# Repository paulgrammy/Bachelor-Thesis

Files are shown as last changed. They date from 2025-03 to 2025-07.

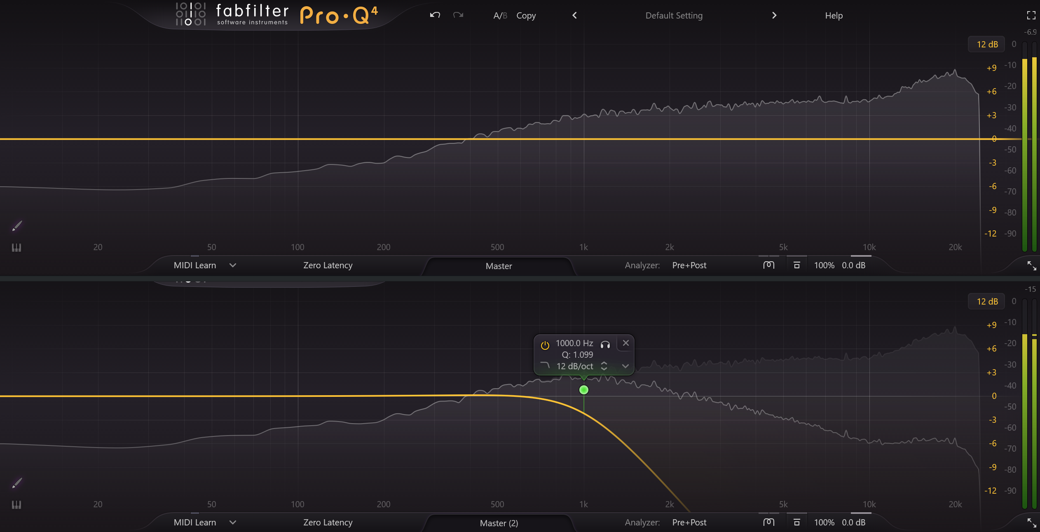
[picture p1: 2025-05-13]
doc/LPF over White Noise Visualised.png

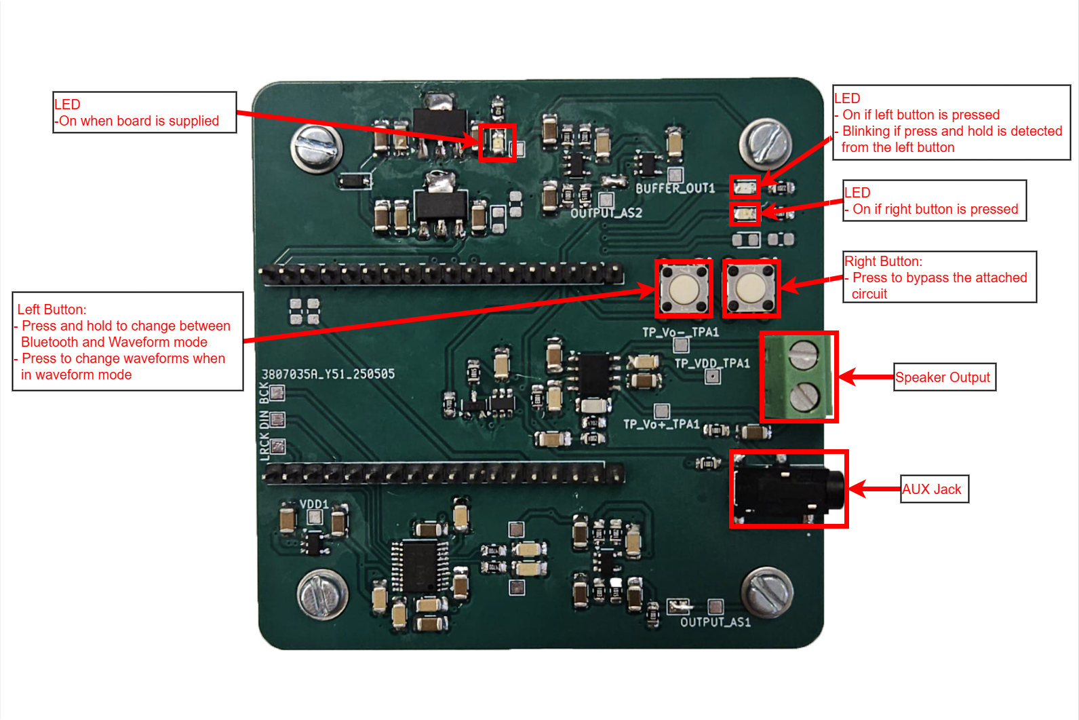
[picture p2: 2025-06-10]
doc/PCB_Functionality.png

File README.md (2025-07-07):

# Bachelor-Thesis

## Introduction and motivation
In recent years, there has been a growing emphasis on learning through hands-on experimentation, particularly in engineering education. One effective way to explore the behavior of electrical components is by using sound signals, which provide an intuitive and immediate way to observe phenomena such as filtering and waveshaping. \newline

My body of work builds on my prior student research project that exemplified this approach using filters. In the project, a prototype was built that takes Bluetooth audio from a source and feeds it through filters studied in electronics labs, thus enabling a better understanding of signal processing concepts. The board then passes the resulting sound to an audio device such as headphones or speakers.

## Requirements and considerations
System-wise, the board shall take +15 V and step it down to supply voltages required by each IC. A 2-layered design is shown, featuring four mounting pins for FestoBoard compatibility. Below, a block diagram is shown, underlying the ICs used for my implementation:

Thesis_Blockdiagram

## Physical view
SMD components alongside SOIC packages for ICs have been used to allow space for all components. Alongside passives and ICs, some buttons and LEDs have been added for user interaction. These shall be handled by the ESP32:

Thesis_PCB

## Software
The ESP32 found on the PCB acts as either:
1) A Bluetooth receiver using [pschatzmann's A2DP library](https://github.com/pschatzmann/ESP32-A2DP);
2) A waveform generator, interfacing via I2S with the DAC to output one of four different waveforms.

FreeRTOS tasks are used to handle the different states of the code:

State Machine Diagram Bachelor Thesis

## Repo structure
* doc: Pictures, Datasheets, Files documenting different aspects of the project
* footprints: different footprints used in the PCB layout
* schematics: KiCAD schematic and layout, and the LTSpice simulation of Op-Amp stages can be found here
* software: the code implementation

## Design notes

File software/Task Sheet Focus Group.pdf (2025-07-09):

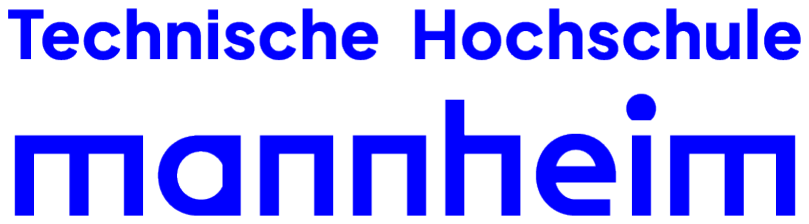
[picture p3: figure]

## Faculty of Electrical Engineering

# Electronics lab

# Signal processing using Audio

made by

Paul Gramescu (2120205)

supervised by

Prof. Dr. Simon Effler

Focus Group

## 1 Objective

- Use the Bluetooth audio board on a FestoBoard to explore the real-time effects of analog filters on audio signals
- Learn how different filter types shape sound and evaluate the usability of the system as a learning tool.

## 2 User Guide

The board used in this lab is meant to feed an audio signal into analog circuits. It is designed to be placed on FestoBoards and features four pins. Below, a photo of the board, along with highlighted important features:

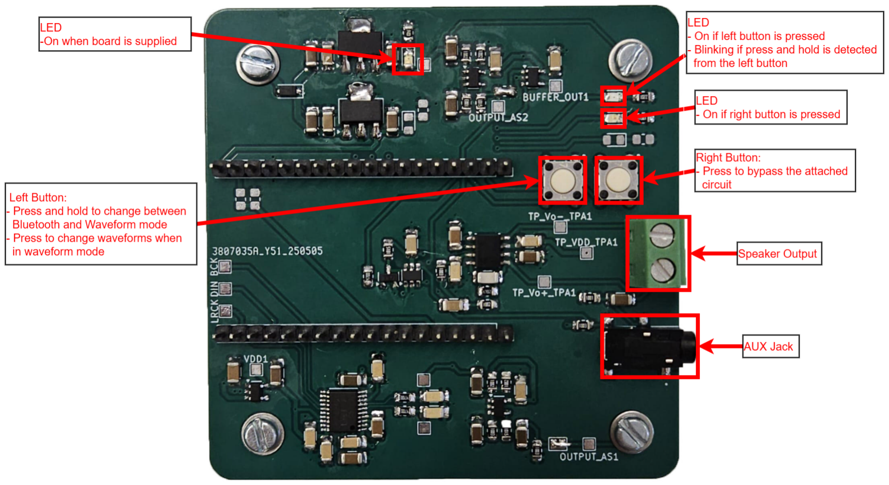
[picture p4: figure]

Abbildung 1: PCB Functionality

Hochschule Mannheim
9. Juni 2025

2

Focus Group

## 3 Setup Instructions

1. Configure the power supply: +15V with a 350mA current limit
2. Connect the audio board:

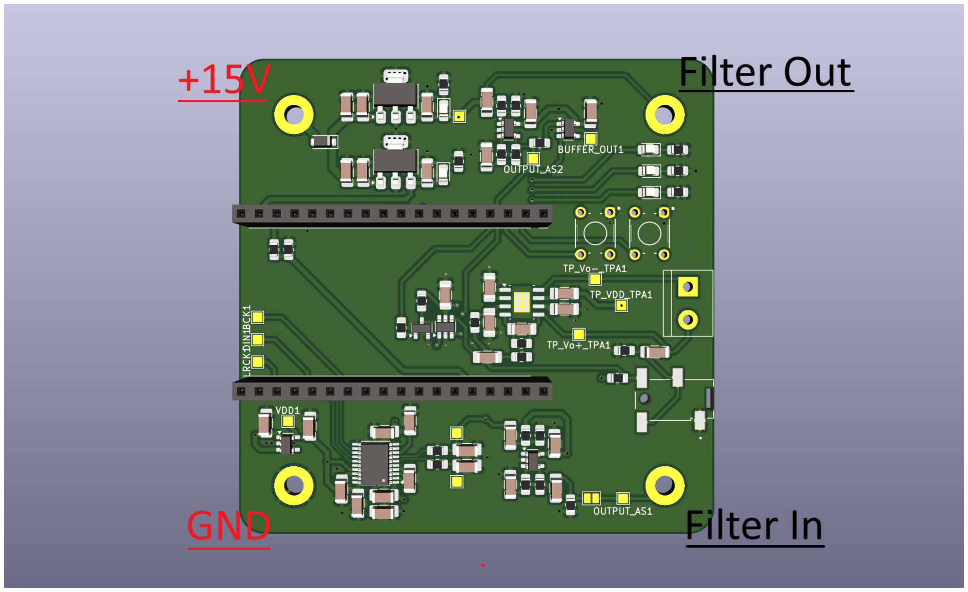
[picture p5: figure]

3. Power on the FestoBoard. If the PCB is connected properly, the topmost LED will turn on, as shown in the user guide section.
4. Connect your phone to the board that corresponds to your desk number
5. Test by playing some audio (e.g., sine sweep, music, voice)
Tip: Press and hold the left button to cycle between Bluetooth/Waveform mode.

If in waveform mode, briefly pressing the same button will cycle through various waveforms. Pressing the right button will bypass the filter circuit.

Hochschule Mannheim
9. Juni 2025

3

Focus Group

## 4 Task No. 1: Filtering high-end frequencies

This task will focus on the effects of low-pass filters on audio signals.

1. Assemble the following active, second-order, low-pass filter:
R1 = 3.2k, R2 = R3 = 10k, C1 = 470nF, C2 = 10nF

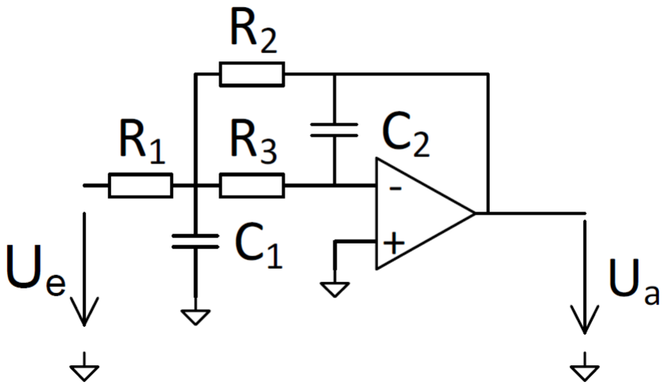
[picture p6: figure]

Abbildung 2: 2nd Order LPF, fc=230Hz

2. Connect Ue to Filter In and Ua to the Filter Out pins of the board
3. Power on the FestoBoard, connect your phone, and verify connectivity
4. Play an audio sample (Ex. Bees Gees - Stayin’ Alive, white noise, a baby crying).
5. Listen and analyse, what do you hear? Why is this happening? Argue your

reasoning
Tip: Use the Bypass function to identify the effect
6. For a more controlled test, use the on-board waveform generator; try cycling between the waveforms

Hochschule Mannheim
9. Juni 2025

4

Focus Group

## 5 Task No. 2: Exploring Filter Orders and Roll-off

This task will explore various filter topologies and their effects.

There are different ways to implement filters. For this case study, three different types of low-pass filters will be used to study their roll-off regions.

IN | OUT

Abbildung 3: 1st-Order, Passive

IN | OUT

Abbildung 4: 2nd-Order, Passive

Abbildung 5: 2nd-Order, Active, same as Task 1

Dimension the circuits with a 230 Hz corner frequency. Use the 5th waveform type (press the right button 4 times). Listen to the output signal and notice the differences

in roll-off. Which topology would be better to use? Why?

Tip: try building a 3rd-order LPF by connecting a 1st-order filter with a 2nd-order in series. What should be the order in which you connect them?

Hochschule Mannheim
9. Juni 2025

5

Focus Group

## 6 Task No. 3: Filtering an unwanted frequency component

This task will show how filters are used to remove unwanted information from a signal.

Say you have a sensor that sends you analog data at a rate of 1.5 kHz. Unfortunately, due to incompetent wiring from your Intern, you receive an additional parasitic, low-frequency component in your signal. This will heavily affect the precision of your measurement and ruin your career. Your task is to analyse the incoming signal and filter the unwanted component:

1. Power on the board and activate Waveform mode
2. Cycle to Waveform 4 (press the button 3 times)
3. Listen to this signal, what do you hear?
4. Analyse in detail: use the Math − > FFT function of the Oscilloscope to analyse

the frequency spectrum
Tip: set the center as 10kHz and the maximum as 20kHz when setting the FFT
5. Conceptualise a second order filter to address the problem
Tip: frequency lies somewhere under your main signal in the spectrum, what does that mean? What would be the cutoff frequency of the filter?
6. Check your result by comparing the un-/bypassed signal path

Hochschule Mannheim
9. Juni 2025

6

Focus Group

### 6.1 Feedback Box

As this was a Focus Group, you are now asked to provide feedback on the exercises, setup, and the board itself.

Feedback:

What did you enjoy in this lab?

What could be improved?

Any additional comments?

Hochschule Mannheim
9. Juni 2025

7

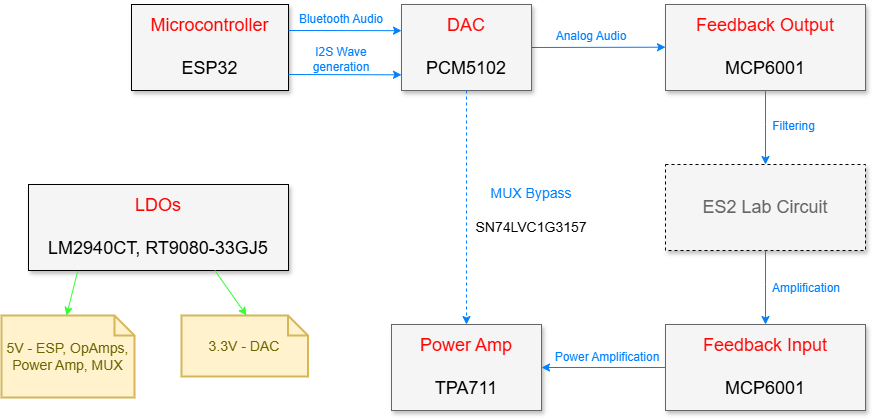
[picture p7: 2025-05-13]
doc/Thesis_Blockdiagram.png

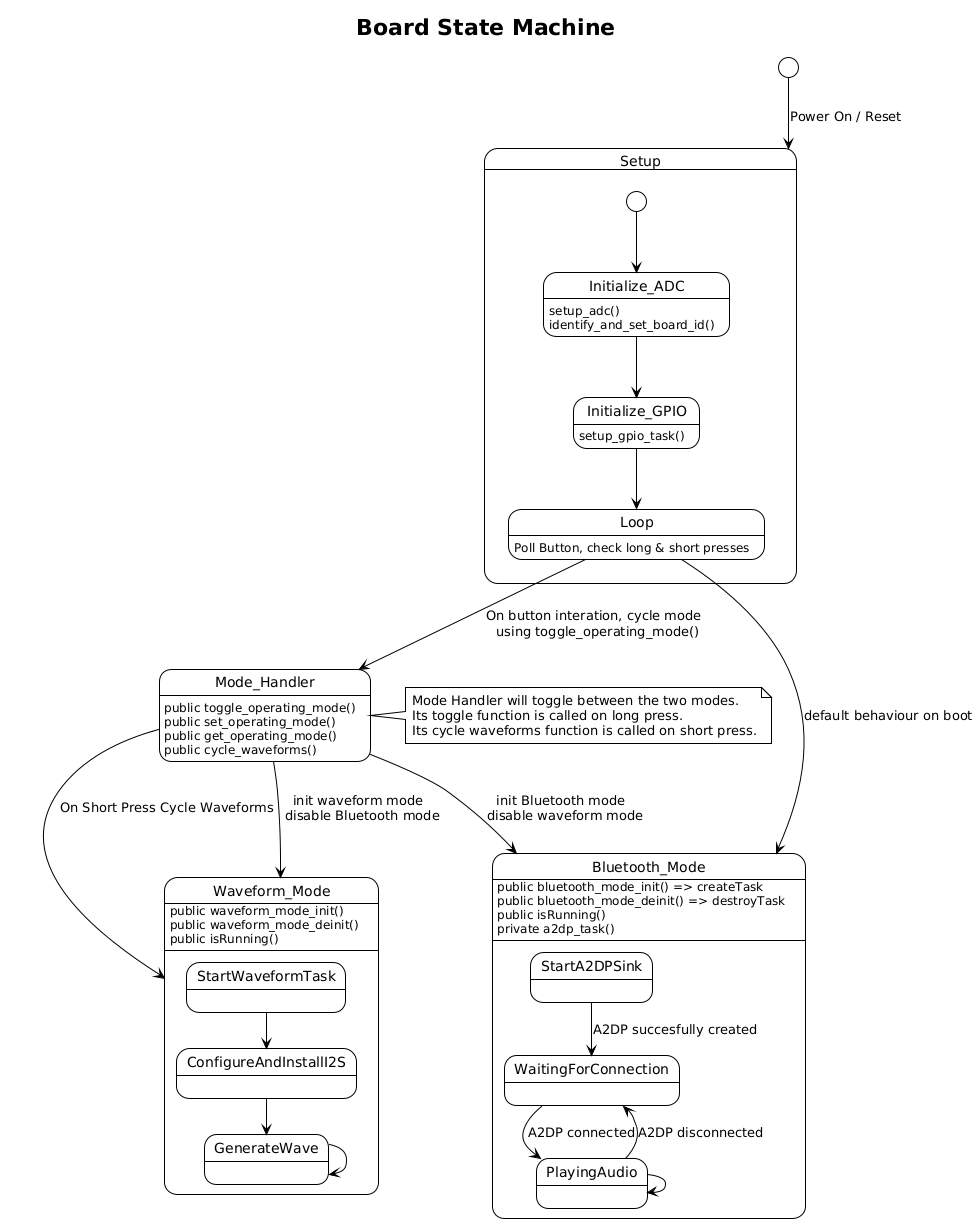
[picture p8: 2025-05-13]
doc/State Machine Diagram Bachelor Thesis.png

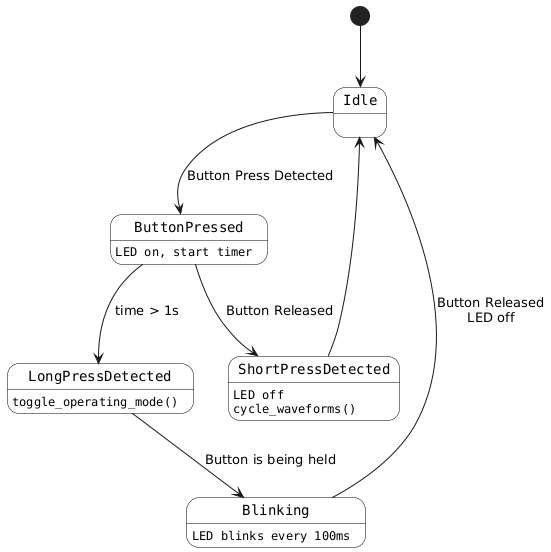
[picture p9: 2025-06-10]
doc/Button Polling State Diagram.png

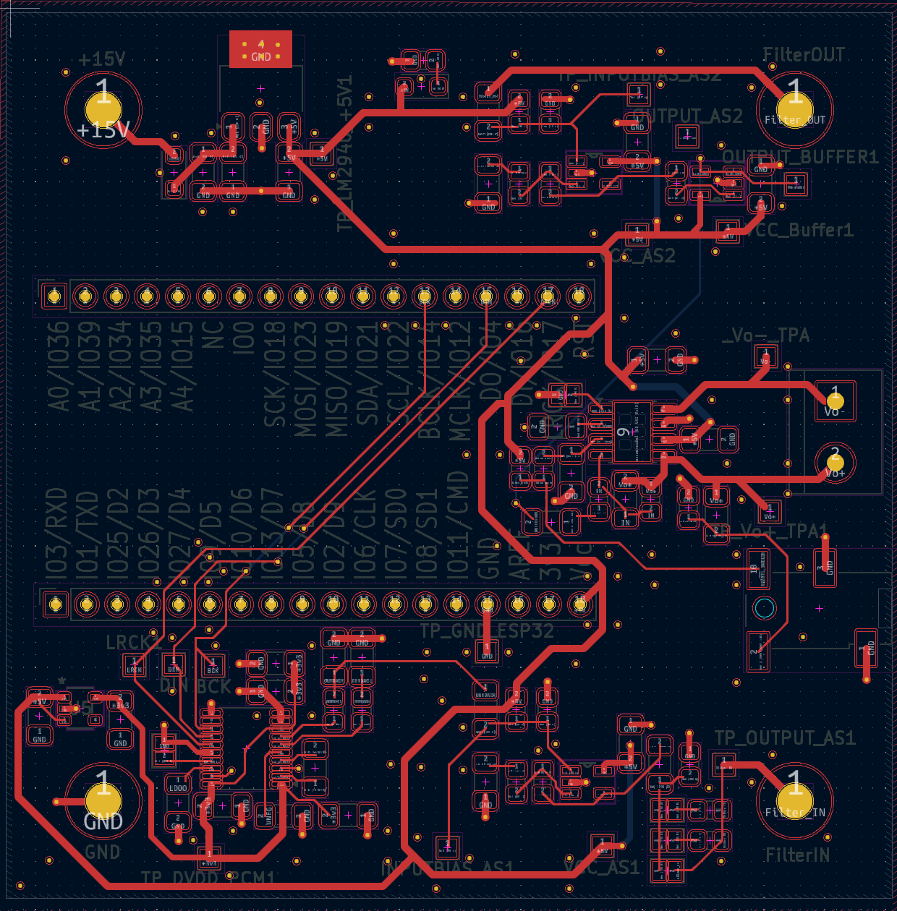
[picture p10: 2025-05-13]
doc/Studienarbeit_PCB.png

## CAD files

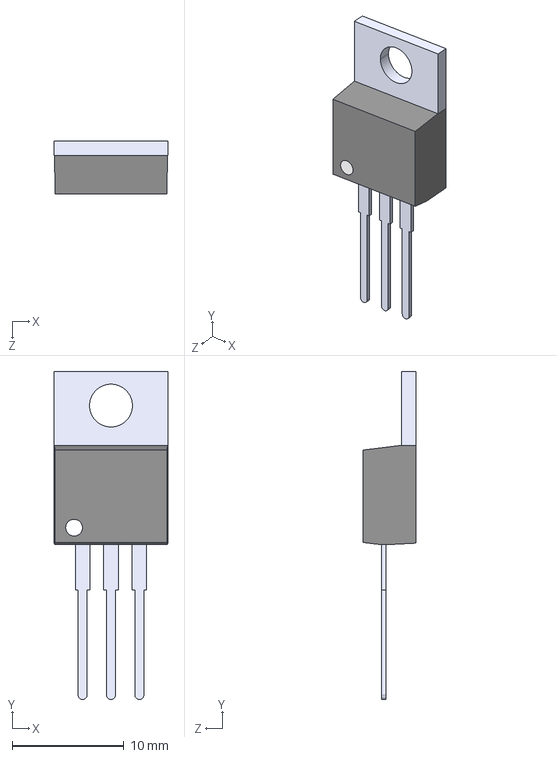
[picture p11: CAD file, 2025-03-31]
footprints/LM2940-5.0/LM2940CT-5.0.step
10.2 x 29.3 x 4.70 mm

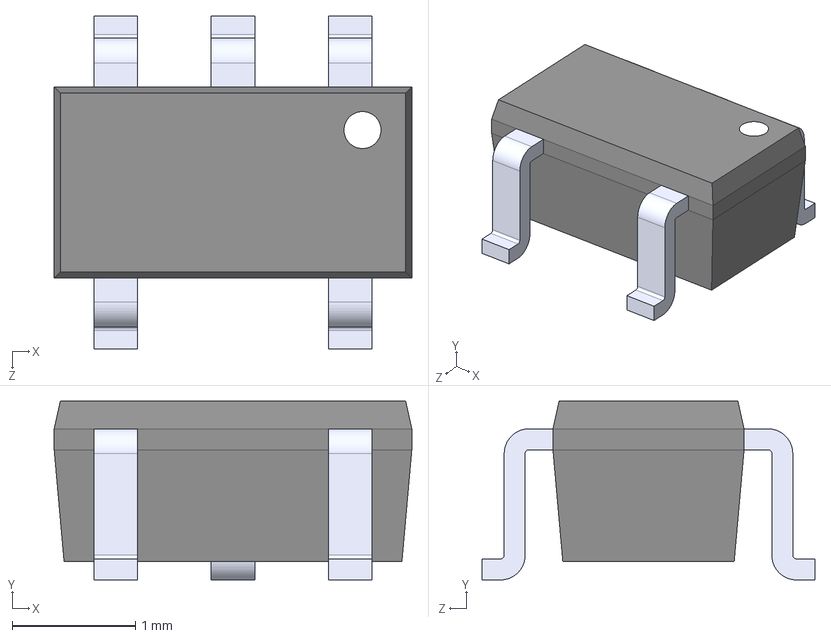
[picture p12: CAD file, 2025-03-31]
footprints/MCP6001UT-1_OT/MCP6001UT-I_OT.step
2.90 x 1.45 x 2.70 mm

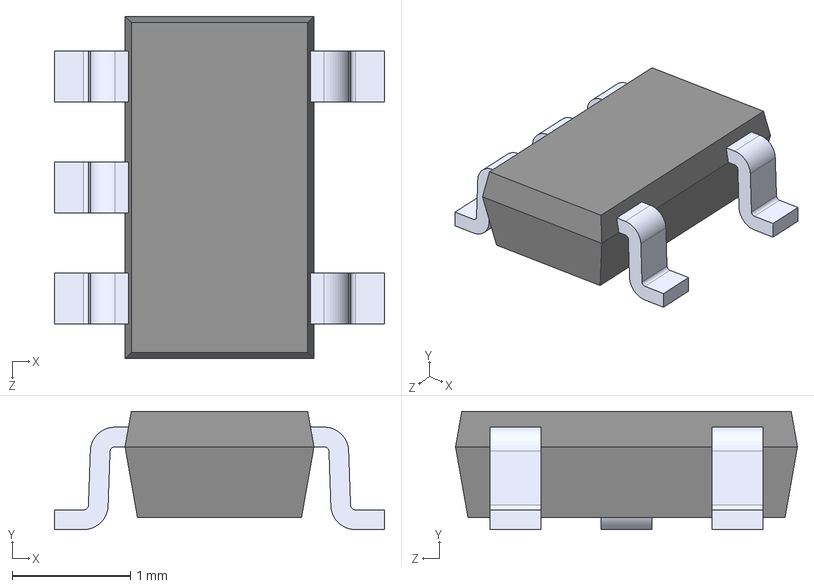
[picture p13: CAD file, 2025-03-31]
footprints/RT9080-33GJ5/RT9080-33GJ5.step
2.80 x 1.00 x 2.90 mm

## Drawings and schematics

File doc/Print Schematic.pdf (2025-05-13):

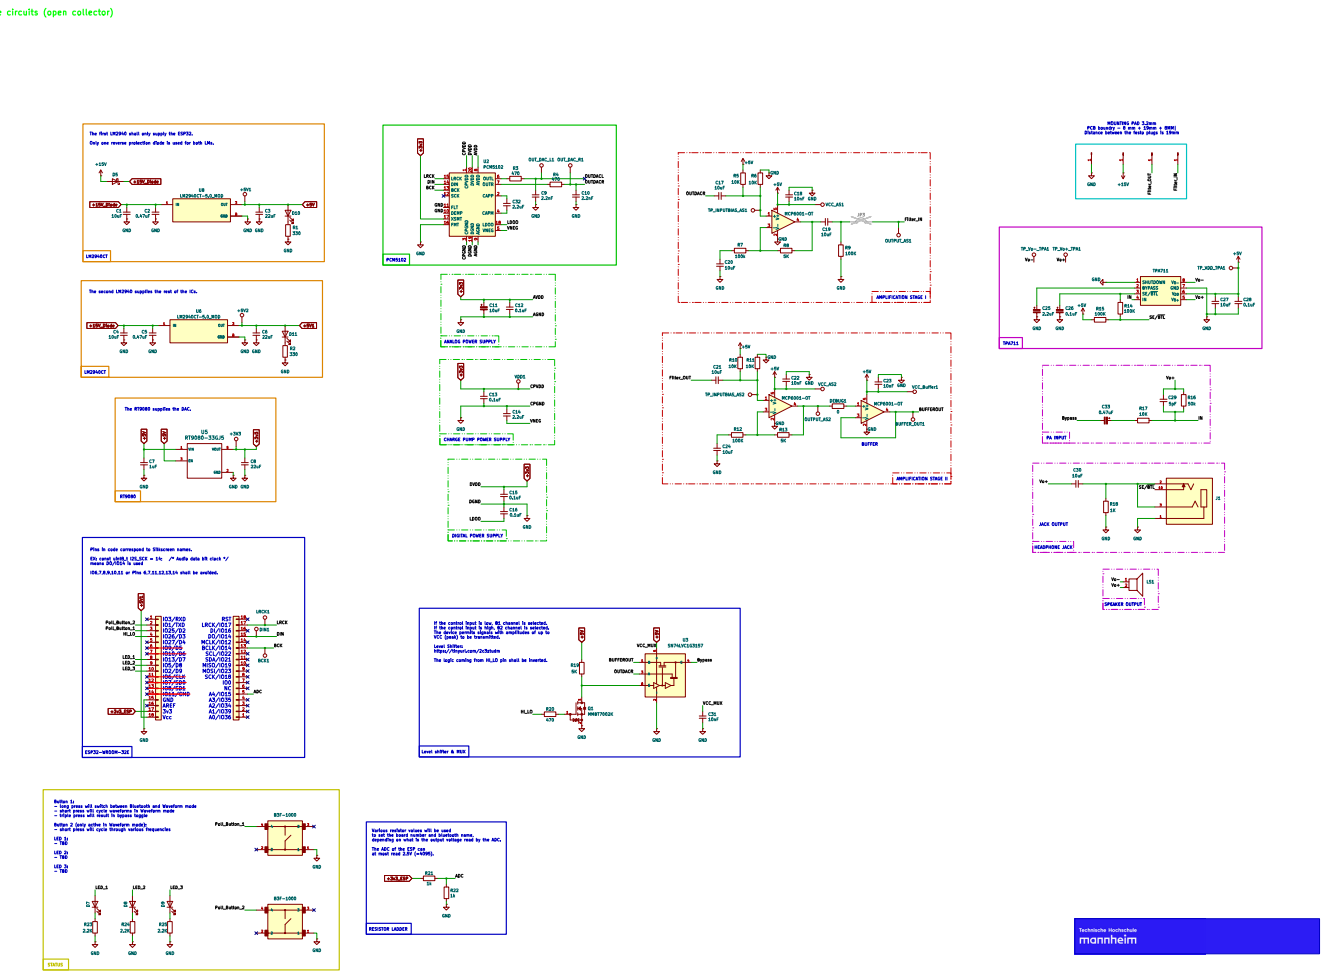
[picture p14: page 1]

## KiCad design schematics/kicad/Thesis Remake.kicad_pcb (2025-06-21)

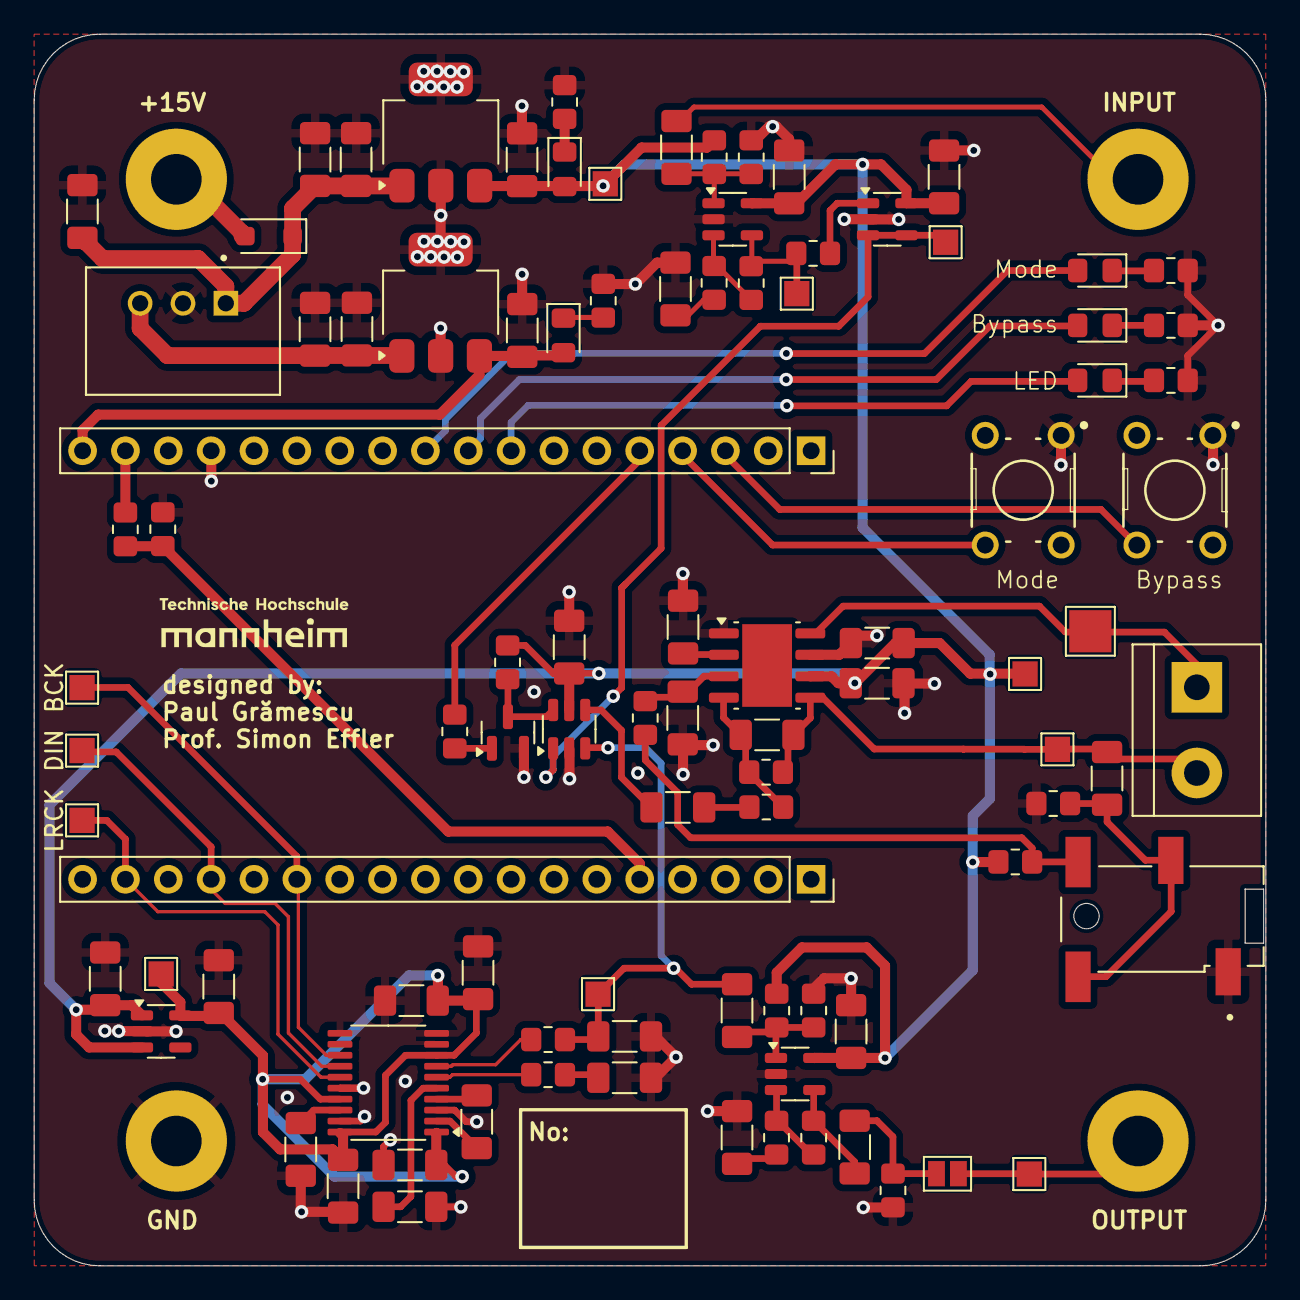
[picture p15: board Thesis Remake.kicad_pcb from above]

Board: 2 copper layers, 73.0 x 73.0 mm, 100 parts (0 on the bottom side), 55 nets.

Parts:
+5V1: TestPoint; TestPoint_Pad_1.5x1.5mm
BCK: TestPoint; TestPoint_Pad_1.5x1.5mm
BUFFER_OUT1: TestPoint; TestPoint_Pad_1.5x1.5mm
C1, C4, C11, C17, C19, C20, C21, C24, C27, C30, C34: 10uF; C_1206_3216Metric_Pad1.33x1.80mm_HandSolder
C2, C5, C33: 0.47uF; C_1206_3216Metric_Pad1.33x1.80mm_HandSolder
C3, C6, C8: 22uF; C_1206_3216Metric_Pad1.33x1.80mm_HandSolder
C7: 1uF; C_1206_3216Metric_Pad1.33x1.80mm_HandSolder
C9, C10: 2.2nF; C_1206_3216Metric_Pad1.33x1.80mm_HandSolder
C12, C13, C15, C16, C26, C28: 0.1uF; C_1206_3216Metric_Pad1.33x1.80mm_HandSolder
C14, C25, C32: 2.2uF; C_1206_3216Metric_Pad1.33x1.80mm_HandSolder
C18, C22, C23, C31: 10nF; C_1206_3216Metric_Pad1.33x1.80mm_HandSolder
C29: 5pF; C_1206_3216Metric_Pad1.33x1.80mm_HandSolder
D5: D_Schottky; D_SOD-123F
D7, D8, D9, D10, D11: LED; LED_0805_2012Metric_Pad1.15x1.40mm_HandSolder
DEBUG1: 0; R_0805_2012Metric_Pad1.20x1.40mm_HandSolder
DIN: TestPoint; TestPoint_Pad_1.5x1.5mm
J1: SJ2-35853B-SMT-TR; CUI_SJ2-35853B-SMT-TR
J2, J3: Conn_01x18; PinSocket_1x18_P2.54mm_Vertical
J4, J5, J6, J7: Conn_01x01_Pin; FestoBoard_Drill_Hole
JP3: Jumper_2_Open; SolderJumper-2_P1.3mm_Open_Pad1.0x1.5mm
LRCK: TestPoint; TestPoint_Pad_1.5x1.5mm
LS1: Speaker; TerminalBlock_bornier-2_P5.08mm
OUTPUT_AS1, OUTPUT_AS2: TestPoint; TestPoint_Pad_1.5x1.5mm
OUT_DAC_R1: TestPoint; TestPoint_Pad_1.5x1.5mm
PS1: TSR_0.5-2465; CONV_TSR_0.5-2465
Q1: MMBT7002K; SOT-23
R1, R2: 330; R_0805_2012Metric_Pad1.20x1.40mm_HandSolder
R3, R4, R20: 470; R_0805_2012Metric_Pad1.20x1.40mm_HandSolder
R5, R6, R10, R11, R17: 10K; R_0805_2012Metric_Pad1.20x1.40mm_HandSolder
R7: 100k; R_0805_2012Metric_Pad1.20x1.40mm_HandSolder
R8, R13, R19: 5K; R_0805_2012Metric_Pad1.20x1.40mm_HandSolder
R9, R12, R14, R15: 100K; R_0805_2012Metric_Pad1.20x1.40mm_HandSolder
R16: 50k; R_0805_2012Metric_Pad1.20x1.40mm_HandSolder
R18: 1K; R_0805_2012Metric_Pad1.20x1.40mm_HandSolder
R21, R22: 1k; R_0805_2012Metric_Pad1.20x1.40mm_HandSolder
R23, R24, R25: 2.2K; R_0805_2012Metric_Pad1.20x1.40mm_HandSolder
S1, S2: B3F-1000; SW_B3F-1000
TP_VDD_TPA1: TestPoint; TestPoint_Pad_1.5x1.5mm
U2: PCM5102; TSSOP-20_4.4x6.5mm_P0.65mm
U3: SN74LVC1G3157; SOT-23-6
U5: RT9080-33GJ5; SOT-23-5
U6, U8: LM2940CT-5.0_MOD; SOT-223
U7: TPA711; Texas_R-PDSO-G8_EP2.95x4.9mm_Mask2.4x3.1mm
U9, U10, U11: MCP6001-OT; SOT-23-5
VDD1: TestPoint; TestPoint_Pad_1.5x1.5mm
Vo+1: TestPoint; TestPoint_Pad_1.5x1.5mm
Vo-1: TestPoint; TestPoint_Pad_2.5x2.5mm

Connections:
+3v3: C8.2, C11.1, C12.2, C13.2, C15.2, U2.1 (CPVDD), U2.8 (AVDD), U2.17 (XSMT), U2.20 (DVDD), U5.5 (VOUT), VDD1.1
+3v3_ESP: J2.17, R21.2
+5V: +5V1.1, C3.2, C7.2, C18.2, C22.2, C23.2, C27.1, C28.1, C31.1, D10.2 (A), R5.2, R10.2, R15.2, R19.2, TP_VDD_TPA1.1, U3.5 (+), U5.1 (VIN), U5.3 (EN), U7.6 (V_{DD}), U8.3 (OUT), U9.5 (V+), U10.5 (V+), U11.5 (V+)
+5V1: C6.2, D11.2 (A), J2.18, U6.3 (OUT)
+6.5V: C4.1, C5.2, PS1.3 (+VOUT), U6.1 (IN)
+15V: D5.2 (A), J5.1
+15V_Diode: C1.1, C2.2, C34.1, D5.1 (K), PS1.1 (+VIN), U8.1 (IN)
/ADC: J3.5, R21.1, R22.1
/BCK: BCK.1, J3.13, U2.13 (BCK)
/BUFFEROUT: BUFFER_OUT1.1, U3.1 (B), U11.3 (-), U11.4
/Bypass: C33.2, U3.4 (C)
/DIN: DIN.1, J3.15, U2.14 (DIN)
/Filter_IN: J7.1, JP3.2 (B), OUTPUT_AS1.1
/Filter_OUT: C21.1, J6.1
/HI_LO: J2.5, R20.1
/IN: C29.1, R16.2, R17.2, U7.4 (IN)
/LDOO: C16.1, U2.18 (LDOO)
/LED_1: D7.2 (A), J2.8
/LED_2: D8.2 (A), J2.9
/LED_3: D9.2 (A), J2.10
/LRCK: J3.17, LRCK.1, U2.15 (LRCK)
/OUTDACL: C9.1, R3.2
/OUTDACR: C10.1, C17.1, OUT_DAC_R1.1, R4.2, U3.3 (A)
/Poll_Button_1: J2.4, S1.4
/Poll_Button_2: J2.3, S2.4
/SE/~BTL: J1.10, R14.1, R15.1
/VNEG: C14.2, U2.5 (VNEG)
/Vo+: C29.2, C30.1, LS1.2, R16.1, U7.5 (V_{O+}), Vo+1.1
/Vo-: LS1.1, U7.8 (V_{O-}), Vo-1.1
GND: C1.2, C2.1, C3.1, C4.2, C5.1, C6.1, C7.1, C8.1, C9.2, C10.2, C11.2, C12.1, C13.1, C14.1, C15.1, C16.2, C18.1, C20.1, C22.1, C23.1, C24.1, C25.2, C26.2, C27.2, C28.2, C31.2, C34.2, J1.1, J2.15, J4.1, PS1.2 (GND), Q1.2, R1.1, R2.1, R6.2, R9.1, R11.2, R18.2, R22.2, R23.1, R24.1, R25.1, S1.1, S2.1, U2.3 (CPGND), U2.9 (AGND), U2.10 (DEMP), U2.11 (FLT), U2.16 (FMT), U2.19 (DGND), U3.2 (-), U5.2 (GND), U6.2 (GND), U6.4 (GND), U7.1 (SHUTDOWN), U7.7 (GND), U8.2 (GND), U8.4 (GND), U9.2 (V-), U10.2 (V-), U11.2 (V-)
unnamed: C19.2, R8.2, U9.4
unnamed: C20.2, R7.1
unnamed: C24.2, R12.1
unnamed: C30.2, J1.2, J1.3, R18.1
unnamed: C33.1, R17.1
unnamed: D7.1 (K), R23.2
unnamed: D8.1 (K), R24.2
unnamed: D9.1 (K), R25.2
unnamed: D10.1 (K), R1.2
unnamed: D11.1 (K), R2.2
unnamed: DEBUG1.1, OUTPUT_AS2.1, R13.2, U10.4
unnamed: C19.1, JP3.1 (A), R9.2
unnamed: Q1.1, R20.2
unnamed: C32.2, U2.4 (CAPM)
unnamed: C32.1, U2.2 (CAPP)
unnamed: R3.1, U2.6 (OUTL)
unnamed: R4.1, U2.7 (OUTR)
unnamed: Q1.3, R19.1, U3.6 (S)
unnamed: C25.1, U7.2 (BYPASS)
unnamed: C26.1, R14.2, U7.3 (SE/~BTL)
unnamed: C17.2, R5.1, R6.1, U9.1 (+)
unnamed: R7.2, R8.1, U9.3 (-)
unnamed: C21.2, R10.1, R11.1, U10.1 (+)
unnamed: R12.2, R13.1, U10.3 (-)
unnamed: DEBUG1.2, U11.1 (+)

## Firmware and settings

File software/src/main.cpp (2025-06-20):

#include <Arduino.h>
#include <ESP_I2S.h>
#include <esp_log.h>

#include "gpio_task.h"
#include "adc_handler.h"
#include "switch_handler.h"
#include "driver/uart.h"

static const char *TAG_MAIN = "MAIN";

void setup()
{
    // Disable UART0 to free GPIO1 before setting up the bypass task, required for button 
    // ESP_LOGI(TAG_MAIN, "Disabling UART...");
    // uart_driver_delete(UART_NUM_0);
    // gpio_reset_pin(GPIO_NUM_1);

    ESP_LOGI(TAG_MAIN, "Starting setup...");

    // Setup ADC
    ESP_LOGI(TAG_MAIN, "Setting up ADC...");
    if (setup_adc() == false)
    {
        ESP_LOGE(TAG_MAIN, "Failed to setup ADC!");
    }
    else
    {
        // ID the board based on voltage
        ESP_LOGI(TAG_MAIN, "Identified board: %s", get_board_id());
    }

    // Setup Button GPIO task
    ESP_LOGI(TAG_MAIN, "Setting up GPIO task...");
    if (setup_gpio_task())
    {
        ESP_LOGI(TAG_MAIN, "GPIO task created successfully.");
    }
    else
    {
        ESP_LOGE(TAG_MAIN, "Failed to create GPIO task!");
    }

    // Setup Bypass GPIO task
    ESP_LOGI(TAG_MAIN, "Setting up Bypass task...");
    if (setup_bypass_task())
    {
        ESP_LOGI(TAG_MAIN, "Bypass task created successfully.");
    }
    else
    {
        ESP_LOGE(TAG_MAIN, "Failed to create Bypass task!");
    }

    ESP_LOGI(TAG_MAIN, "Setup succesfully completed.");

    // Blink LED to indicate setup is complete
    // Setup LED GPIO
    gpio_set_direction(GPIO_NUM_5, GPIO_MODE_OUTPUT);           // Setup Internal LED

    gpio_set_level(GPIO_NUM_5, 1);                              // Turn LED on
    vTaskDelay(pdMS_TO_TICKS(500));                             // Delay to allow LED to turn on
    gpio_set_level(GPIO_NUM_5, 0);                              // Turn LED off
}

void loop() {}

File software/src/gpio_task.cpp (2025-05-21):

#include "gpio_task.h"

static const char *TAG_BUTTON_TASK = "GPIO_TASK";
static uint8_t task_parameters;                                 // Task parameters, unused but still defined
static TaskHandle_t gpioHandle = NULL;                          // When task created successfully, this will hold the address in memory of the task
const gpio_num_t button_pin = (gpio_num_t)BUTTON_PIN;           // GPIO pin for the button, default is 25
// definitions
bool setup_gpio_task(void)
{
    bool isSuccesful = false;

    ESP_LOGI(TAG_BUTTON_TASK, "Setting up GPIO task...");
    gpio_set_direction(button_pin, GPIO_MODE_INPUT);            // Set the GPIO pin as input
    gpio_set_pull_mode(button_pin, GPIO_PULLUP_ONLY);           // Set the GPIO pin to pull-up mode

    gpio_set_direction(GPIO_NUM_2, GPIO_MODE_OUTPUT);           // Setup Internal LED

    xTaskCreatePinnedToCore(gpio_event_loop,
                "GPIO Task",
                GPIO_STACK_SIZE,
                &task_parameters,
                TASK_PRIORITY,
                &gpioHandle,
                1);                                   // Create the task with the function gpio_event_loop() and pass the task parameters to it

    if (gpioHandle == NULL)                                     // Check if the task has been created
    {
        isSuccesful = false;

        ESP_LOGE(TAG_BUTTON_TASK, "Failed to create GPIO task!");
    }
    else
    {
        isSuccesful = true;

        ESP_LOGI(TAG_BUTTON_TASK, "GPIO task created successfully!");
    }
    toggle_operating_mode();                                    // Kickstart bluetooth operation
    vTaskDelay(pdMS_TO_TICKS(500));                             // Delay to allow task to initialize

    return isSuccesful;
}

static void gpio_event_loop(void *pvParameters)
{
    ESP_LOGI(TAG_BUTTON_TASK, "GPIO event Loop started...");

    TickType_t start_time = 0;
    bool button_pressed = false;                                // Button pressed state
    bool last_button_state = true;                              // Default HIGH (pull-up)
    bool blinking = false;                                      // Flag to mark blinking state
    bool has_triggered_long_press = false;                      // Flag to mark long press state

    while (true)
    {
        bool current_button_state = gpio_get_level(button_pin); // PULL-UP => true = not pressed

        if (!current_button_state && last_button_state)         // HIGH to LOW transition = detected press
        {
            start_time = xTaskGetTickCount();
            button_pressed = true;
            has_triggered_long_press = false;
            gpio_set_level(GPIO_NUM_2, 1);                      // Turn LED on to indicate button press

            ESP_LOGI(TAG_BUTTON_TASK, "Button pressed!");
        }

        // Detect release
        if (current_button_state && !last_button_state && button_pressed)
        {
            button_pressed = false;                             // Mark Button release
            blinking = false;                                   // Stop blinking
            gpio_set_level(GPIO_NUM_2, 0);                      // Turn LED off to be safe
            TickType_t elapsed_time = xTaskGetTickCount() - start_time;

            if (elapsed_time < pdMS_TO_TICKS(1000))
            {
                cycle_waveforms();                              // Cycle through waveforms

                ESP_LOGI(TAG_BUTTON_TASK, "Button released, short press!");
            }
        }

        if (button_pressed && !has_triggered_long_press)        // If button is held and hasn't triggered long press action yet
        {
            TickType_t held_time = xTaskGetTickCount() - start_time;
            if (held_time > pdMS_TO_TICKS(1000))
            {
                has_triggered_long_press = true;
                blinking = true;                                // Start blinking because button is held

                ESP_LOGI(TAG_BUTTON_TASK, "Button released, long press and hold!");
                toggle_operating_mode();                        // Toggle operating mode

            }
        }

        // Blinking logic (blinks only if blinking = true and button still held)
        static bool led_state = false;
        static TickType_t last_blink_time = 0;
        if (blinking && !current_button_state)
        {
            TickType_t now = xTaskGetTickCount();
            if ((now - last_blink_time) > pdMS_TO_TICKS(100))   // Counter for 100ms
            {
                led_state = !led_state;                         // Toggle LED state
                gpio_set_level(GPIO_NUM_2, led_state);
                last_blink_time = now;                          // Update last blink time
            }
        }

        last_button_state = current_button_state;
        vTaskDelay(pdMS_TO_TICKS(30));                          // Smoother loop
    }
}

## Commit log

2025-03-31 Couple of imports from Student-Research.
    [LM2940CT-5.0.step, MCP6001UT-I_OT.step, RT9080-33GJ5.step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]
2025-03-31 Added PCB file.
    [Thesis.kicad_pcb, Thesis.kicad_sch]
2025-04-21 Added LED blinking to test later on HW.
2025-05-13 code commits
    [Thesis Remake.kicad_pcb, Thesis Remake.kicad_sch]
2025-05-21 Bluetooth works. Waveform generation glitches due to continuous generation.
    [Thesis Remake.kicad_pcb, Thesis Remake.kicad_sch]
2025-06-10 Bluetooth works. Waveform generation works.
    [Thesis Remake.kicad_sch]
2025-06-10 Uneori nu inteleg de ce folosesc GitHub....
2025-06-16 QOL PCB changes
    [Thesis Remake.kicad_pcb]
2025-06-16 Moved the buttons one pin lower to avoid TX
    [switch_handler.cpp]
2025-06-17 Moved bypass switch from Pin 25 to 27 temp
2025-06-20 Updated PCB.
    [Thesis Remake.kicad_pcb, Thesis Remake.kicad_sch]
2025-06-20 Added the TH Logo on the board.
    [Thesis Remake.kicad_pcb]
2025-06-21 Updated schematic in main
    [Thesis Remake.kicad_pcb, Thesis Remake.kicad_sch]
